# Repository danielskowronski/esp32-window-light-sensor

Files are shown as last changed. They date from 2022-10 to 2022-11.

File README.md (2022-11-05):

# ESP32 based Window Light Sensor with HomeKit and MQTT support

Used as a sensor for automatic shades closure when it's too bright for delicate eyes of nerd. Added temperature sensor as cheap addition to I2C bus.

HomeKit for automation, MQTT for reporting to HomeAssistant. 

## Software

Arduino sketch - [./software/esp32-window-light-sensor/](./software/esp32-window-light-sensor/)

### Libraries

- ESP32 v2.0.5
- HomeSpan
    - until https://github.com/HomeSpan/HomeSpan/issues/414 is resolved, fork https://github.com/danielskowronski/HomeSpan is required for "upgraded" Home
- BH1750 v1.3.0
- BMP280 v2.6.6

## Hardware

ESP32 board connected to light and temperature sensors via ribbon cable - [./hardware/HARDWARE.md](./hardware/HARDWARE.md)

## Usage

### HomeKit

Follow [HomeSpan User Guide](https://github.com/HomeSpan/HomeSpan/blob/master/docs/UserGuide.md)

### MQTT

TBD (not yet implemented)

### Label

To get label like this, follow [./label/LABEL.md](./label/LABEL.md)

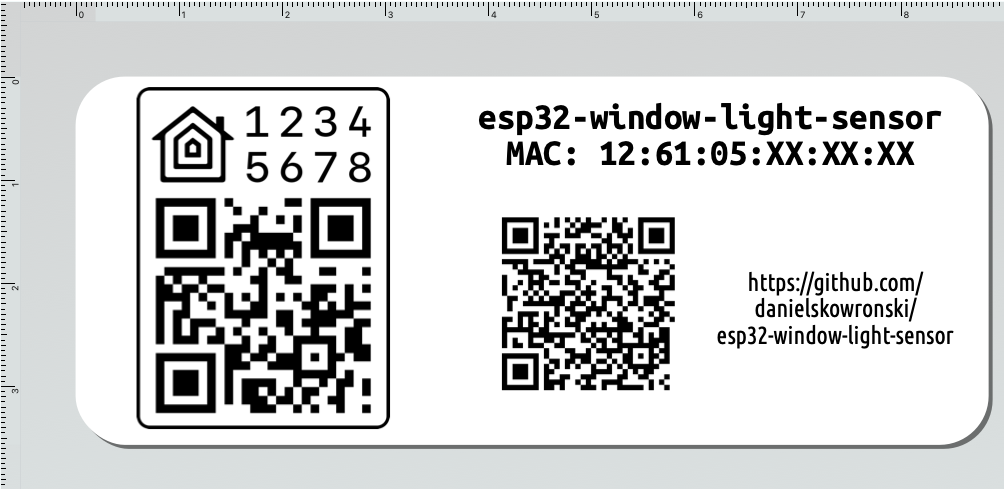
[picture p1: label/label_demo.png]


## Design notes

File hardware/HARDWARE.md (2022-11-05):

# Hardware

## Bill of Materials

- MCU: ESP32 Dev Board - see [MCU.md](MCU.md)
- light sensor: **BH1750** (`BH1750FVI`) in GY-302 kit
- temperature sensor: **BMP280** in HW-611 kit
- 5x7cm double-sided prototype board, KYNAR wires
- IDC10 board connector: 2x angled
- IDC10 terminated ribbon cable to be routed at edge of window glass (so it can be behind shades), 3m
- plastic case - Kradex Z34B

### Light sensor selection

- photoresistor: random accuracy, external ADC required
- phototransistor TEMT6000: <570nm, external ADC required
- BH1750: cheap, +/-20% accurate
- TSL2581FN: more precise, but no ready-made integration, not easily available in reasonable package
- TSL25911: seems the best, but not easily available at all

### Cable selection

4 lines would be enough, but IDC10 is easier to obtain and is mure rigid. Future iterations may repurpose USB cable.

## Schematic

Fritzing project: [esp32-lightsensor.fzz](esp32-lightsensor.fzz)

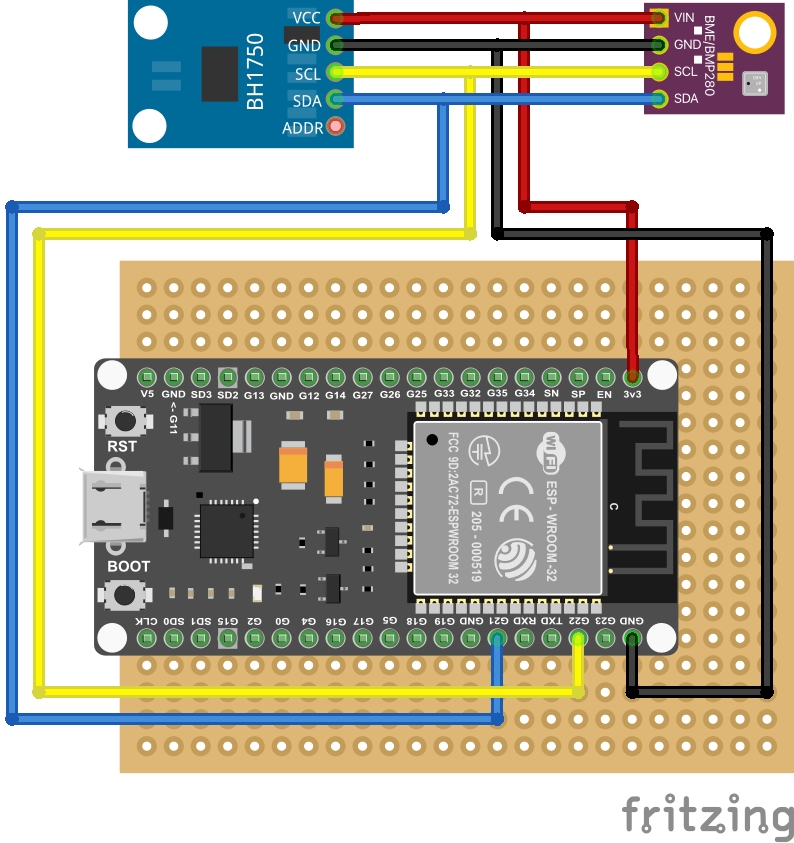
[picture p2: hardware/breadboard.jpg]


## I2C

### BMP280

Pulling **CSB** pin low will turn I2C off and activate SPI. On short wires I2C may be active even if **CSB** is left floating, but it really should be linked to **VDD**!

I2C address is `0x76` when **SDO** pin is pulled low or floating, pulling it high will switch it to `0x77`. I2C address can be switched at any moment.

To set address in code, update following line in [`../software/esp32-window-light-sensor.ino`](../software/esp32-window-light-sensor.ino):

```c
#define BMP280_I2C_ADDRESS 0x76
```

### BH1750

I2C address is `0x23` when **SDO** pin is pulled low or floating, pulling it high will switch it to `0x5C`.

To set address in code, update following line in [`../software/esp32-window-light-sensor.ino`](../software/esp32-window-light-sensor.ino):

```c
#define BH1750_I2C_ADDRESS 0x23
```

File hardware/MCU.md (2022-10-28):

# ESP-WROOM-32

**ESP32-D0WDQ6 Rev 1 dual-core 4MB Flash**
Features: WiFi, BT, Dual Core, 240MHz, VRef calibration in efuse, Coding Scheme None
Crystal is 40MHz

Pinout: [https://cdn.shopify.com/s/files/1/0609/6011/2892/files/doc-esp32-pinout-reference-wroom-devkit.png](https://cdn.shopify.com/s/files/1/0609/6011/2892/files/doc-esp32-pinout-reference-wroom-devkit.png)

Arduino IDE config:

- Board: ESP32 Dev Module (`esp32`)
- Flash mode: QOUT
- Upload speed: 460800

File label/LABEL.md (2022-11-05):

## Label

This document shows how to prepare 36x89mm (*Large Address*) DYMO Label that can be sticked to top of proposed case - Kradex Z34B. It assumes you use ***DYMO Label*** software and have *label* printer connected.

It'll look like that: 



### Instructions

1. First, set up HomeKit Pairing Code (default from HomeSpan is 466-37-726). To do so, connect via serial and issue `S 12345678` where `12345678` is desired code.
   You'll get confirmation and line saying: `Setup Payload for Optional QR Code: X-HM://XXXXXXXXXAAAA`. You'll need to get that `AAAA` part as this is `setupId`.
1. Next step is to get MAC address of the ESP32 board, which in this project is set as HomeKit device Serial Number. 
   Issue command `i` over serial and look for like `Characteristic SerialNumber`.
1. Then, you can generate HomeKit Label. NPM package `homekit-code` seems the easiest one to do the job.
   ```bash
   npx homekit-code qrcode --category=bridge --pairingCode=12345678 --setupId=AAAA --name=esp32-window-light-sensor --output=png
   ```
1. After that, open [./label.label](./label.label) with ***DYMO Label***.
    1. Replace HomeKit QR code by copying contents of `esp32-window-light-sensor.png`, double clicking on image in DYMO Label and selecting *clipboard* as image source. 
    1. Replace MAC address on Text object.
    1. Print it.

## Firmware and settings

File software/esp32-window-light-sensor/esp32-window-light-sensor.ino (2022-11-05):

#define VER "0.2"
#define BMP280_I2C_ADDRESS 0x76
#define BH1750_I2C_ADDRESS 0x23

#include <Wire.h>
#include "HomeSpan.h" 
#include "Identify.h"      
#include "LightSensor.h"
#include "TemperatureSensor.h"
#include <WiFi.h>

void setup() {
  Serial.begin(115200);

  homeSpan.begin(Category::Bridges,"esp32-window-light-sensor Bridge");
  new SpanAccessory();  
    new Identify("esp32-window-light-sensor Bridge","DS",WiFi.macAddress().c_str(),"esp32-window-light-sensor Bridge", VER ,3);
    new Service::HAPProtocolInformation();
      new Characteristic::Version("1.1.0");
      
  new SpanAccessory();                                                          
    new Identify("esp32-window-light-sensor Light Sensor","DS",WiFi.macAddress().c_str(),"esp32-window-light-sensor Light Sensor", VER, 5);
    new LightSensor();

  new SpanAccessory();                                                          
    new Identify("esp32-window-light-sensor Temperature Sensor","DS",WiFi.macAddress().c_str(),"esp32-window-light-sensor Temperature Sensor", VER, 7);
    new TemperatureSensor();
}

void loop(){
  homeSpan.poll(); 
}

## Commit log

2022-10-28 MVP with HomeKit only and simplest photoresistor
    [esp32-lightsensor.fzz]
2022-11-05 prototype next version with proper light sensor and case+cable
    [esp32-lightsensor.fzz]
2022-11-05 initial code for light and temperature sensors, add hardware specs
    [esp32-lightsensor.fzz]
2022-11-05 error handling, hardware spec update
    [esp32-window-light-sensor.ino]
